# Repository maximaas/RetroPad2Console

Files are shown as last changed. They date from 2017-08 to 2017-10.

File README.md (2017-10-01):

# RetroPad2Console

for SNES & Saturn pads using on original xbox and gamecube.

Copyright (C) 2015,2017 Maximaas<br/>
Version 1.0 - completed on 2015.12.09

<H2>About</H2>
Original Xbox and Nintendo Gamecube(Europe version) are good emulator platforms with RGB video support, which makes it possible to play retro games on a RGB capable CRT display. But with weird controller scheme, the default Xbox and GC controller are disasters for most retro games. So I came up with the idea of making an adapter to let me use SNES and Saturn pads on these consoles. Saturn pad has six buttons on the right, it's perfect for MegaDrive and 2D-Fighting games while SNES pad is for NES/SNES/GBP and other games.

<H2>References</H2>
Before I start, I googled a lot of resources to help me accomplish this project (see blow). Greate thanks to all these authors.<br/><br/>

http://www.int03.co.uk/crema/hardware/gamecube/gc-control.htm<br/>
Gamecube controlle protocol explanation.

http://www.raphnet.net/electronique/x2wii/index_en.php<br/>
N64/Snes/Nes controller to gamecube/Wii conversion project

https://github.com/brownan/Gamecube-N64-Controller<br/>
I directly used the gamecube communication code from this project with just a little modification. It helps me greatly, without this I will never done my work.

http://www.brunofreitas.com/node/41<br/>
https://github.com/bootsector/usb-retropad-adapter<br/>
A very powerful adapter, I directly used the Xbox pad communication code from this project or I will never got my project work on original xbox.

<H2>Pictures</H2>

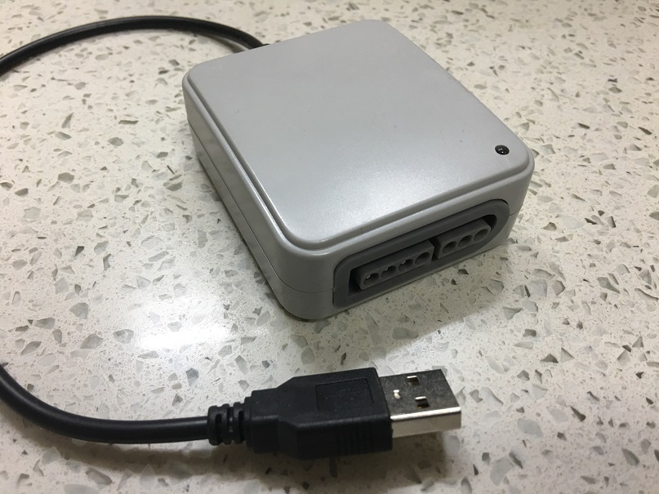
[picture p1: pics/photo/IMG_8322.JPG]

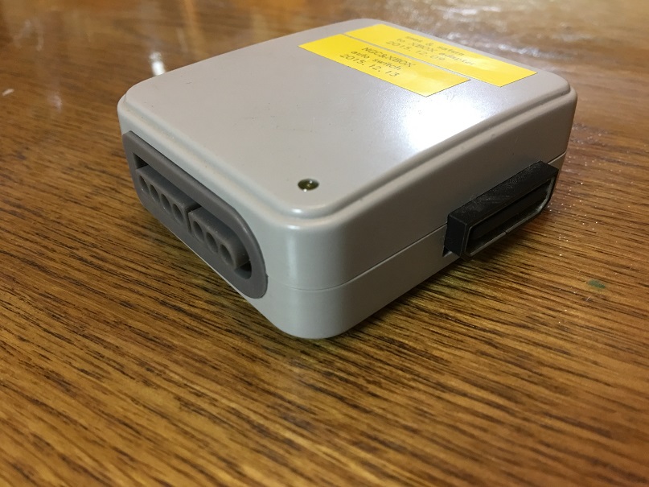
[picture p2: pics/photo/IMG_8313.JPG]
<br/>
I bought several SNES to PC adapters to make use of its case and snes female connector.

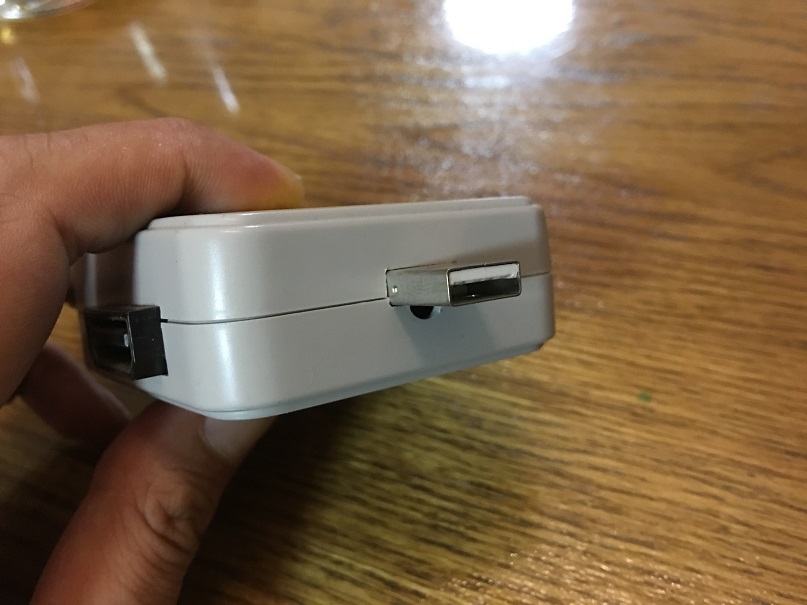
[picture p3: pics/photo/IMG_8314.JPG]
<br/>
My work uses USB connector as the output in order to adapt both Xbox and GC.

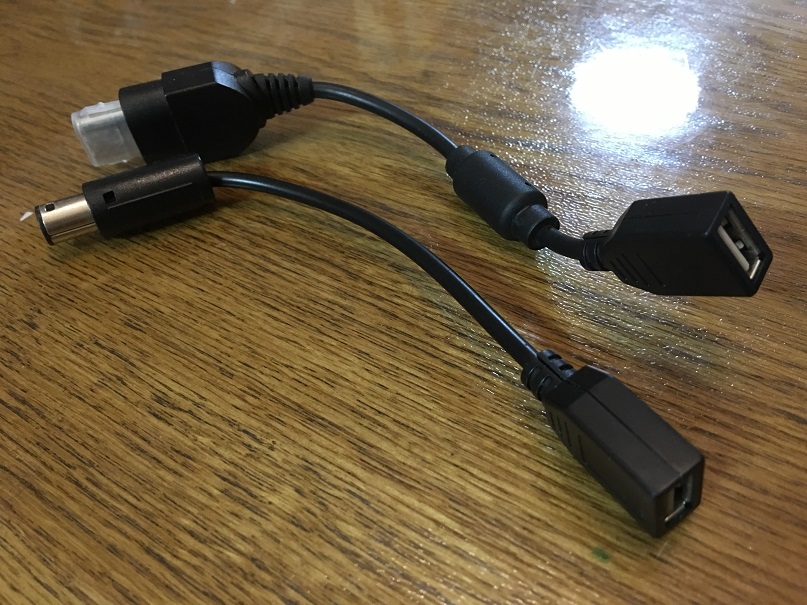
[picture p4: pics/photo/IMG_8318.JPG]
<br/>
Interface cable. Female USB connector to Xbox and GC controller port.

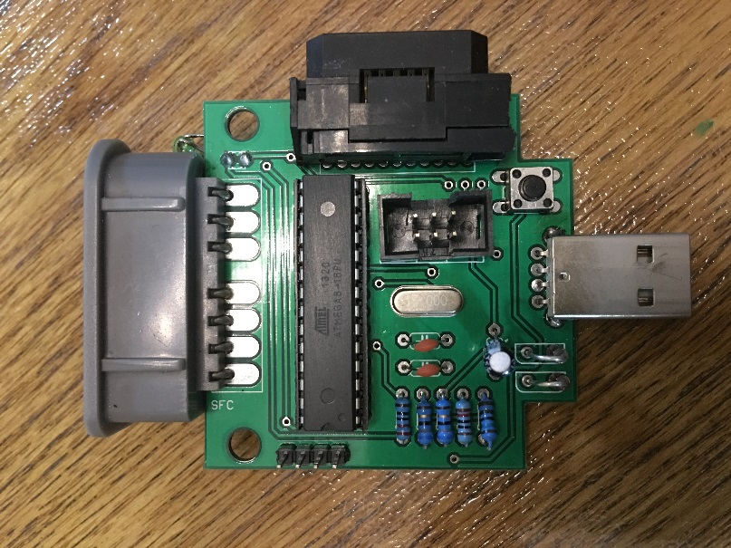
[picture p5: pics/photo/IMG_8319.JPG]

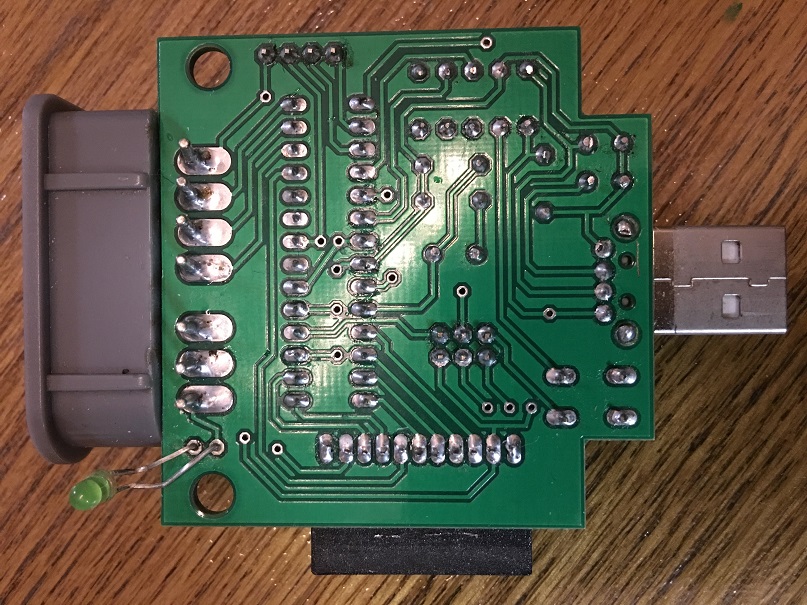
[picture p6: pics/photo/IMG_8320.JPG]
<br/>
The PCB I designed with the size fits with the SNES to PC adapter case. And a bit of hand craft work should be done to accommodate the Saturn and USB connectors.

<H2>Parts</H2>

| Parts | Model | Remark |
|:---|:---|:---|
| MCU | ATMEGA8-16PU | Can be replaced with ATMEGA328p for more program memory |
| CRYSTAL  | 16 MHz | |
| R_RST | 120 Ohm | |
| R_LED | 220 Ohm | |
| R_USB | 1.5K Ohm | |
| R_D+ | 68 Ohm | |
| R_D- | 68 Ohm | |
| C1 | 22 pf | |
| C2 | 22 pf | |
| C3 | 4.7 uf | |
| D1 | 1N4148 | |
| D2 | 1N4148 | |
| SWITCH | Reset Switch | |
| LED | Any 5v LED | |
| USB-A | / | USB-A Male connector |
| SFC | / | SFC conenctor |
| SS | / | SS connector |
| | | |
| GC Cable | / | NGC extesion cable |
| XB Cable | / | XBOX extension cable |
| USB | / | USB-A female connector |

<H2>Build the Adapter</H2>
This adapter is actually a minimum Arduino based on ATMEGA8-16PU. It receives the SNES/Saturn pad signals then interprete and send them to the target according to Xbox or GC protocol.

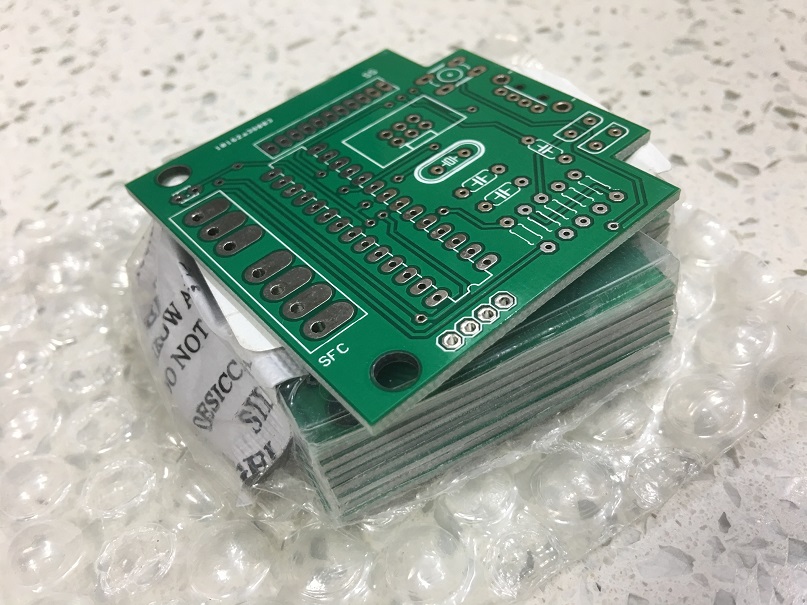
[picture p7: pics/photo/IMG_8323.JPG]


The eagle files of the hardware part are included. The PCB have both ICSP and Serial interfaces on it, for bootloader and firmware programming.

The software part is standard Arduino sketch codes, can be compiled and uploaded with Arduino IDE.

With the parts assembled, upload the "optiboot_atmega8" bootloader by ICSP which can be found in Arduino IDE releases. 

The firmware can be uploaded by either ICSP or Serial interface. For Serial way, the reset button need to be hit right after you clicked the upload button in Arduino IDE.

BTW, I'm using Sloeber IDE(http://eclipse.baeyens.it/) to help keeping my Arduino projects well organized.

<H2>Interface cable wiring</H2>

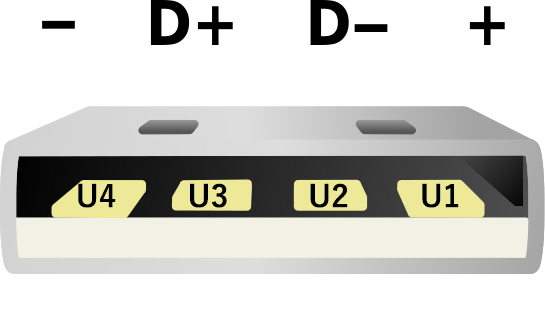
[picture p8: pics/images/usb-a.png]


Here's a picture of male usb connector, I named the 4 pins to U1/U2/U3/U4, then wired them to the consoles' controller port.

<ul>
<li>Xbox</li>
</ul>
The adapter uses the standard usb pinout and V-USB library to communicate with Xbox which makes the wiring things very simple.

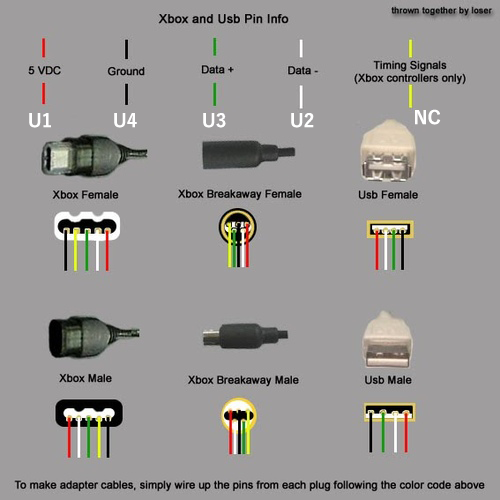
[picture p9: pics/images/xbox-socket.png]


Just follow the image above.

<ul>
<li>Gamecube</li>
</ul>
Gamecube only have one data line to carry the signal which connected to PD2(D+ pin) in my case.

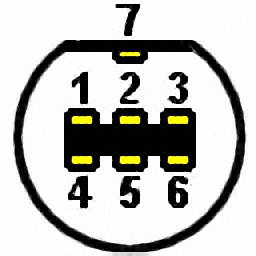
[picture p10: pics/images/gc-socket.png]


It is the view of the controller port on Gamecube.<br/>
pin1   --> U1<br/>
pin2   --> U3<br/>
pin4&5 --> U4<br/>
The D- line is left empty.<br/>

<H2>Known Issues</H2>
<ul>
<li>The turning on of the LED on the adapter means the handshaking process is over and the adapter is funtional. Unlike the Gamecube, the Xbox will not do the handshaking process with the controller until the power on video clip is finished. When cold-plugged to the Xbox the adapter will be funtional after the console started.</li>
<br/>
<li>The adapter can not work with Game Boy Interface (a replacement to the official Gameboy Player application) because of a different handshaking protocol. The ATMEGA8-16PU only have 8KB memory, adding any fix codes will cause it reachs it's physical limit.</li>
</ul>

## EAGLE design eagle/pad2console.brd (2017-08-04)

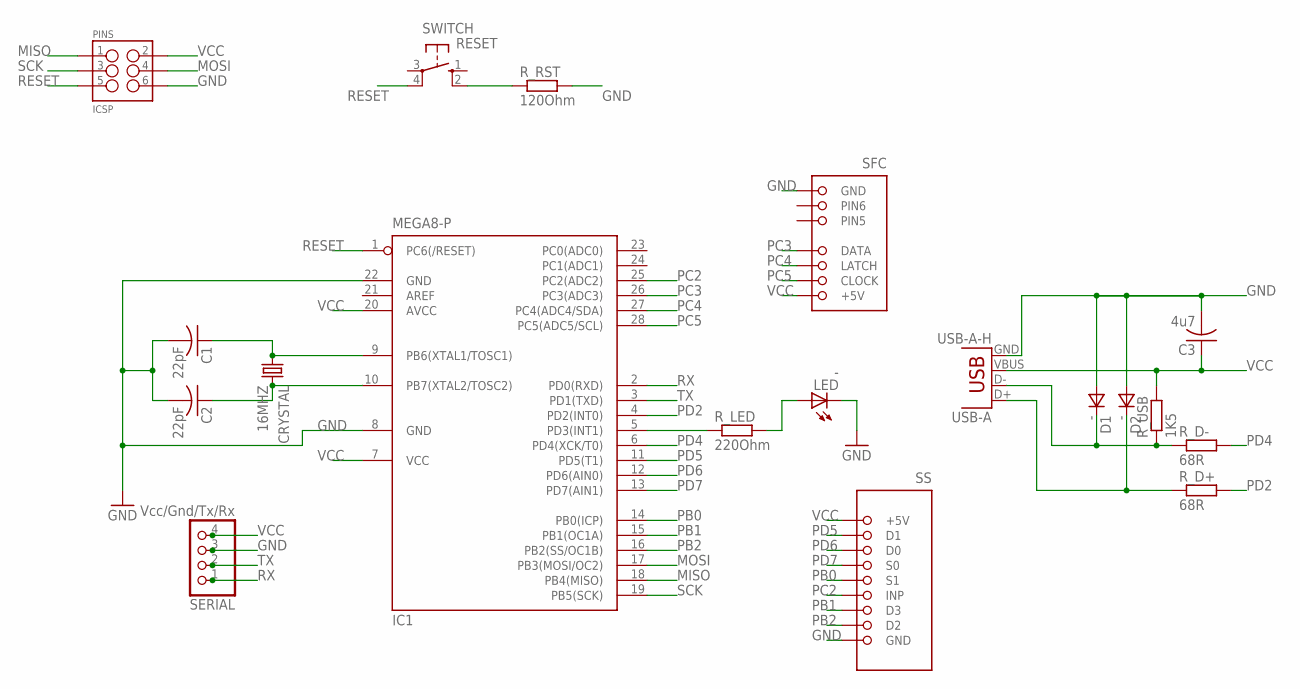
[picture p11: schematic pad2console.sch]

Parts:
C1, C2: 22pF; C050-024X044
C3: 4u7; C050-024X044
CRYSTAL: 16MHZ; HC49/S
D1, D2: -; E2LINE
IC1: MEGA8-P; DIL28-3
LED: -; LD260
PINS: ICSP; 2X3-SHROUDED
R_D+: 68R; 0204/5
R_D-: 68R; 0204/5
R_LED: 220Ohm; 0204/5
R_RST: 120Ohm; 0204/5
R_USB: 1K5; 0204/5
SERIAL: Vcc/Gnd/Tx/Rx; 1X04
SFC: SFC_PIN
SS: SS_PIN
SWITCH: RESET; B3F-10XX
USB-A: USB-A-H

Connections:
D+: D2.1 (C), R_D+.1, USB-A.D+
D-: D1.1 (C), R_D-.1, R_USB.1, USB-A.D-
GND: C1.2, C2.2, C3.2, D1.2 (A), D2.2 (A), IC1.8 (GND), IC1.22 (GND), LED.K (C), PINS.6, R_RST.2, SERIAL.3, SFC.PIN7 (GND), SS.PIN9 (GND), USB-A.GND
MISO: IC1.18 (PB4(MISO)), PINS.1
MOSI: IC1.17 (PB3(MOSI/OC2)), PINS.4
unnamed: LED.A, R_LED.2
unnamed: R_RST.1, SWITCH.2 (S1)
PB0: IC1.14 (PB0(ICP)), SS.PIN5 (S1)
PB1: IC1.15 (PB1(OC1A)), SS.PIN7 (D3)
PB2: IC1.16 (PB2(SS/OC1B)), SS.PIN8 (D2)
PB6: C1.1, CRYSTAL.1, IC1.9 (PB6(XTAL1/TOSC1))
PB7: C2.1, CRYSTAL.2, IC1.10 (PB7(XTAL2/TOSC2))
PC2: IC1.25 (PC2(ADC2)), SS.PIN6 (INP)
PC3: IC1.26 (PC3(ADC3)), SFC.PIN4 (DATA)
PC4: IC1.27 (PC4(ADC4/SDA)), SFC.PIN3 (LATCH)
PC5: IC1.28 (PC5(ADC5/SCL)), SFC.PIN2 (CLOCK)
PD2: IC1.4 (PD2(INT0)), R_D+.2
PD3: IC1.5 (PD3(INT1)), R_LED.1
PD4: IC1.6 (PD4(XCK/T0)), R_D-.2
PD5: IC1.11 (PD5(T1)), SS.PIN2 (D1)
PD6: IC1.12 (PD6(AIN0)), SS.PIN3 (D0)
PD7: IC1.13 (PD7(AIN1)), SS.PIN4 (S0)
RESET: IC1.1 (PC6(/RESET)), PINS.5, SWITCH.4 (P1)
RX: IC1.2 (PD0(RXD)), SERIAL.1
SCK: IC1.19 (PB5(SCK)), PINS.3
TX: IC1.3 (PD1(TXD)), SERIAL.2
VCC: C3.1, IC1.7 (VCC), IC1.20 (AVCC), PINS.2, R_USB.2, SERIAL.4, SFC.PIN1 (+5V), SS.PIN1 (+5V), USB-A.VBUS

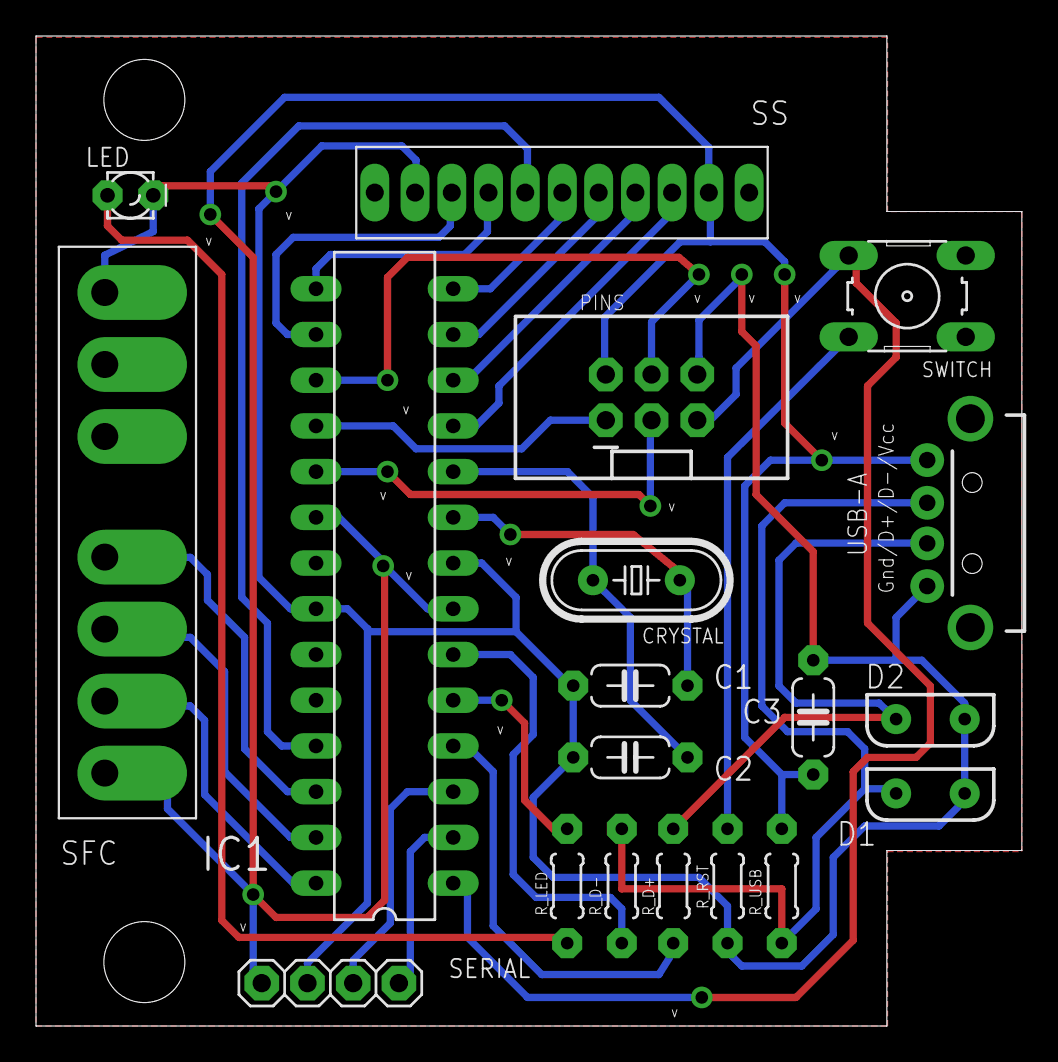
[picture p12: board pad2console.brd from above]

Board: 2 copper layers, 54.8 x 55.0 mm, 19 parts (0 on the bottom side), 27 nets.

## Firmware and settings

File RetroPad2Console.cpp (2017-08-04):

/**
 * RetroPad2Console
 * for SNES & Saturn pads using on original xbox and gamecube.
 *
 * Copyright (C) 2015,2017 Maximaas
 * Version 1.0 - completed on 2015.12.09
 *
 * GNU GPLv3 license
 *
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
 * Contact: mingzo@gmail.com
 */
#include "RetroPad2Console.h"

#include "ConsoleEuroGC.h"
#include "ConsoleXbox.h"

#include "XBOXPad.h"
#include "SnesPad.h"
#include "SaturnPad.h"

#define PIN_LED 3

//pads
SnesPad pad_snes = SnesPad();
SaturnPad pad_saturn = SaturnPad();

//consoles
ConsoleEuroGC ngc = ConsoleEuroGC();
ConsoleXbox xbox = ConsoleXbox();

bool xb = false;
bool gc = false;

void setup()
{
	//Serial.begin(9600);

	pinMode(PIN_LED, OUTPUT);

	//Detect which console currently connected
	gc = ngc.communicate(true);

	//if not a ngc, looping to wait for the xbox
	while (!gc && !xb) {
		//Initiate ports and settings for xbox console...
		xbox_init(false);

		//Serial.println("Establishing communication with xbox console...");
		//Try 5 times, if not work, means the connected target is not a xbox.
		for (int i=0; i<5; i++) {
			xbox_reset_watchdog();
			delayMicroseconds(10000); // 10ms delay
			xbox_send_pad_state();

			if (xbox_pad_detected()) {
				xb = true;
				break;
			}
		}
	}

	//turn the led on when any console detected
	if (gc || xb) {
		digitalWrite(PIN_LED, HIGH);
	}

	pad_snes.init();
	pad_snes.wait();

	pad_saturn.init();
	pad_saturn.wait();
}

void loop()
{

	//console is xbox
	if (xb) {
		xbox.idle();

		if (pad_snes.connected) {
			int snes_state = pad_snes.buttons();
			if (snes_state > 0) {
				xbox.snes(snes_state);
			}
		}
		if (pad_saturn.connected) {
			int* saturn_state = pad_saturn.buttons();
			if (saturn_state[4] > 0) {
				xbox.saturn(saturn_state);
			}
		}

		xbox_send_pad_state();
	}

	//console is gamecube
	if(gc) {
		ngc.reset();

		if (pad_snes.connected) {
			int snes_state = pad_snes.buttons();
			if (snes_state > 0) {
				ngc.snes2gc(snes_state);
			}
		}

		if (pad_saturn.connected) {
			int* saturn_state = pad_saturn.buttons();
			if (saturn_state[4] > 0) {
				ngc.saturn2gc(saturn_state);
			}
		}
		ngc.communicate(false);
	}
}

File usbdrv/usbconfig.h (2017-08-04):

/*
* USB RetroPad Adapter - PC/PS3 USB adapter for retro-controllers!
* Copyright (c) 2012 Bruno Freitas - bootsector@ig.com.br
*
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
* You should have received a copy of the GNU General Public License
* along with this program.  If not, see <http://www.gnu.org/licenses/>.
 */

#ifndef __usbconfig_h_included__
#define __usbconfig_h_included__

/* ---------------------------- Hardware Config ---------------------------- */

#define USB_CFG_IOPORTNAME      D
/* This is the port where the USB bus is connected. When you configure it to
 * "B", the registers PORTB, PINB and DDRB will be used.
 */
#define USB_CFG_DMINUS_BIT      4
/* This is the bit number in USB_CFG_IOPORT where the USB D- line is connected.
 * This may be any bit in the port.
 */
#define USB_CFG_DPLUS_BIT       2
/* This is the bit number in USB_CFG_IOPORT where the USB D+ line is connected.
 * This may be any bit in the port. Please note that D+ must also be connected
 * to interrupt pin INT0! [You can also use other interrupts, see section
 * "Optional MCU Description" below, or you can connect D- to the interrupt, as
 * it is required if you use the USB_COUNT_SOF feature. If you use D- for the
 * interrupt, the USB interrupt will also be triggered at Start-Of-Frame
 * markers every millisecond.]
 */
#define USB_CFG_CLOCK_KHZ       16000
//#define USB_CFG_CLOCK_KHZ       (F_CPU/1000)
/* Clock rate of the AVR in kHz. Legal values are 12000, 12800, 15000, 16000,
 * 16500, 18000 and 20000. The 12.8 MHz and 16.5 MHz versions of the code
 * require no crystal, they tolerate +/- 1% deviation from the nominal
 * frequency. All other rates require a precision of 2000 ppm and thus a
 * crystal!
 * Since F_CPU should be defined to your actual clock rate anyway, you should
 * not need to modify this setting.
 */
#define USB_CFG_CHECK_CRC       0
/* Define this to 1 if you want that the driver checks integrity of incoming
 * data packets (CRC checks). CRC checks cost quite a bit of code size and are
 * currently only available for 18 MHz crystal clock. You must choose
 * USB_CFG_CLOCK_KHZ = 18000 if you enable this option.
 */

/* ----------------------- Optional Hardware Config ------------------------ */

/* #define USB_CFG_PULLUP_IOPORTNAME   D */
/* If you connect the 1.5k pullup resistor from D- to a port pin instead of
 * V+, you can connect and disconnect the device from firmware by calling
 * the macros usbDeviceConnect() and usbDeviceDisconnect() (see usbdrv.h).
 * This constant defines the port on which the pullup resistor is connected.
 */
/* #define USB_CFG_PULLUP_BIT          4 */
/* This constant defines the bit number in USB_CFG_PULLUP_IOPORT (defined
 * above) where the 1.5k pullup resistor is connected. See description
 * above for details.
 */

/* --------------------------- Functional Range ---------------------------- */
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

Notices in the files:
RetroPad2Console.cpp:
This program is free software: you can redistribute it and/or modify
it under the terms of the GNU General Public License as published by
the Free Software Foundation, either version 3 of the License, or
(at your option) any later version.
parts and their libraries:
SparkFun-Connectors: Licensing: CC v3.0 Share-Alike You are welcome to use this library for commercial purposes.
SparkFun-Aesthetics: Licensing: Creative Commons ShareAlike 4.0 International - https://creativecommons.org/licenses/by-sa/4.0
